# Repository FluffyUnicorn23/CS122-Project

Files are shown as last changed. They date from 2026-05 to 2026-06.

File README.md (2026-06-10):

# CS122A Custom Laboratory Project

# PID Seesaw Balancer

**Ricky Vo and Isaiah Tirado**
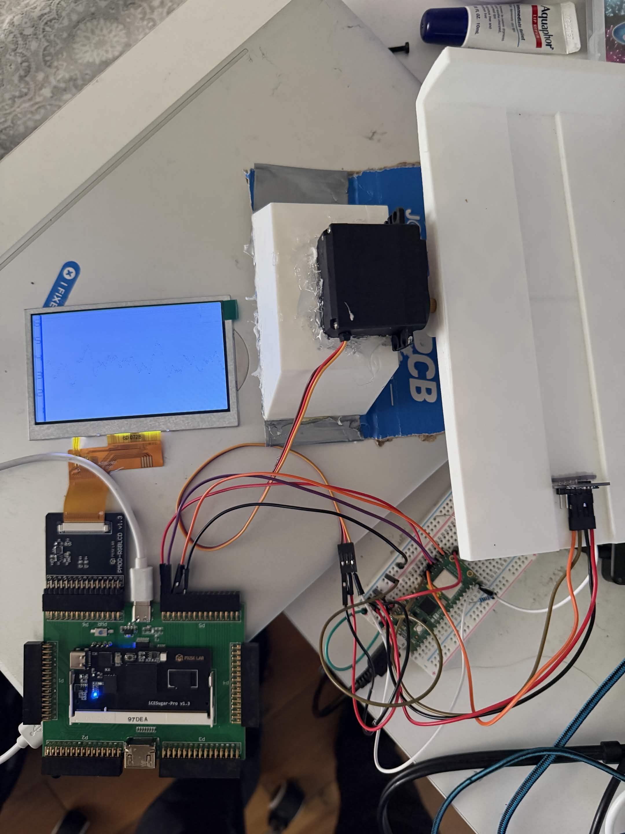
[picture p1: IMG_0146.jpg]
Visual Image

---

# Introduction

A custom printed seesaw attempts to keep a ball as stationary as possible at the target through PID. The seesaw is tilted through a servo motor.

Our PID constants are:

- **Kp = 0.5**
- **Kd = 0.15**
- **Ki = 0.05**
- **Interval Time = 25 ms**

The default target distance used to keep the ball stationary is set to **3 inches** away from the Time-of-Flight sensor. The target distance can be incremented through a button that also starts the balancing procedure, with implemented value rollover.

The distance of the ball from the sensor is tracked through a graph displayed on a screen powered by the FPGA.

Overall, we found that the constants stated above provided the most consistent performance without causing the ball to enter an unstable state.

### Software Issues

- Potential for the system to become unstable.
- Visual display bugs such as double-printed information.

### Hardware Issue

- The seesaw must be manually held down because it is tilted.

---

# Elements of Complexity

- Accurate PID calculations that cause the ball to balance at the desired target.
- Custom designed graph.
- Custom PLA 3D prints designed in OnShape (first time using the software).

---

# User Guide

1. Reset / Power the MCUs.
2. Hold the seesaw down.
3. Place a tennis ball on the seesaw.
4. Press the button.
5. Let it do its magic.
6. Press the button again to increase the target distance.

---

# Hardware Components Used

- IceSugar / IceSugar-Pro FPGA
- RGB LCD from the required lab components
- Raspberry Pi Pico
- MG946R Servo Motor
- VL53L0X Time-of-Flight Sensor
- Custom 3D Printed PLA Seesaw and Complementary Base

---

# Software Libraries Used

- VL53L0X library by yspreen
- pico_stdlib
- Pico I2C library
- Pico SPI library
- Pico PWM library

---

# Protocols Used

## SPI

Used to send information to the FPGA to display necessary data on the RGB LCD.

Signals used:

- MOSI
- CS
- Clock

## I2C

Used for communication with the VL53L0X Time-of-Flight sensor.

- Device Address: `0x29`

---

# Requirements

### IceSugar / IceSugar-Pro FPGA

Used to power and control the information displayed on the RGB LCD screen.

### RGB LCD

Displays positional information of the ball.

### Raspberry Pi Pico

Controls the servo motor, obtains positional information from the Time-of-Flight sensor, and sends information to the FPGA.

### Event Driven Execution

Has a button that turns on the balancing procedure and increments target distance only when pressed.

---

# Wiring Diagram

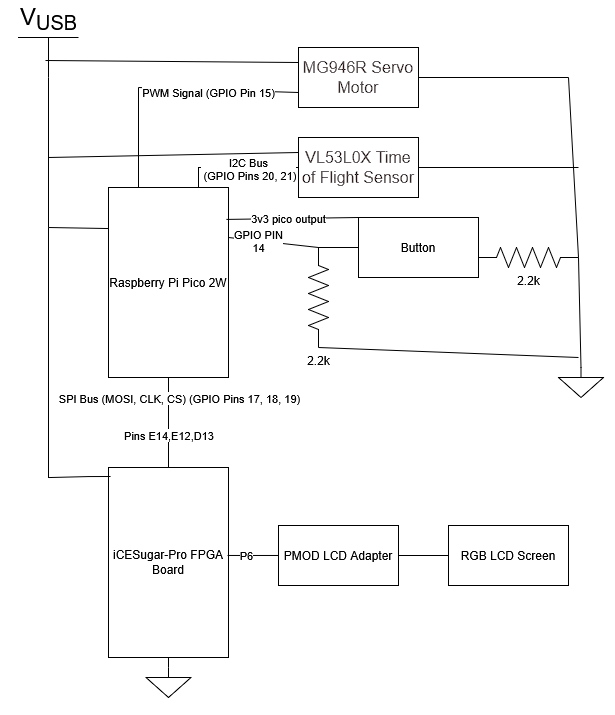
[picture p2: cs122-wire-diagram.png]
Wiring Diagram


---

# Design Diagram

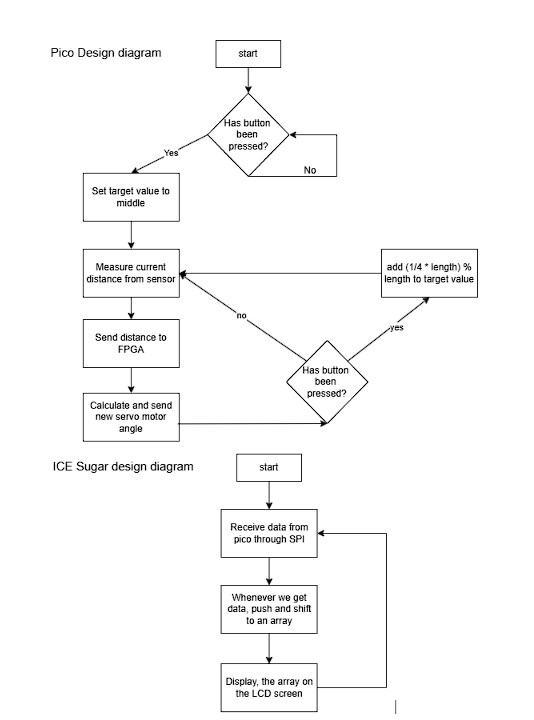
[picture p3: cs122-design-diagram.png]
Design Diagram


---

# AI Usage

**Ricky:** I used AI for the PWM code and the constraint code by asking Google Search.

---

# Acknowledgements

VL53L0X Driver by yspreen:

https://github.com/yspreen/VL53L0X-driver-pico-sdk-cpp/blob/main/VL53L0X.h

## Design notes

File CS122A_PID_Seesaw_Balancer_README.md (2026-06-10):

# CS122A Custom Laboratory Project
## PID Seesaw Balancer

**Authors:** Ricky Vo and Isaiah Tirado

---

## Overview

A custom 3D-printed seesaw balances a ball at a configurable target position using a PID controller. The seesaw angle is adjusted by a servo motor while a VL53L0X Time-of-Flight sensor continuously measures the ball's position.

### PID Configuration

| Parameter | Value |
|---|---|
| Kp | 0.50 |
| Ki | 0.05 |
| Kd | 0.15 |
| Update Interval | 25 ms |

The default target position is **3 inches** from the sensor. A push button starts the balancing process and increments the target distance with rollover behavior. Ball position is displayed graphically on an FPGA-driven LCD screen.

---

## Features

- PID-controlled ball balancing
- Adjustable target position
- Real-time position tracking
- FPGA-powered graphical display
- Custom-designed 3D printed mechanical system
- Event-driven operation through push-button input

---

## Project Complexity

### Control System
- Accurate PID calculations for stable ball balancing
- Real-time feedback control using Time-of-Flight sensing

### Embedded Systems
- Communication between Raspberry Pi Pico and FPGA
- SPI-based display updates
- I2C sensor integration
- PWM servo motor control

### Mechanical Design
- Custom PLA 3D-printed seesaw and base
- Designed using OnShape

---

## User Guide

1. Power on or reset the microcontrollers.
2. Hold the seesaw in place.
3. Place the tennis ball on the seesaw.
4. Press the button to start balancing.
5. Press the button again to increase the target distance.

---

## Hardware Components

| Component | Purpose |
|---|---|
| IceSugar / IceSugar Pro FPGA | LCD control and graphics |
| RGB LCD | Position visualization |
| Raspberry Pi Pico | Main controller |
| MG946R Servo Motor | Seesaw actuation |
| VL53L0X Time-of-Flight Sensor | Ball position sensing |
| Custom 3D Printed PLA Parts | Mechanical structure |

---

## Software Libraries

- Modified VL53L0X library by yspreen
- pico_stdlib
- Pico I2C library
- Pico SPI library
- Pico PWM library

---

## Communication Protocols

### SPI
Used to transmit display information from the Raspberry Pi Pico to the FPGA.

Signals used:
- MOSI
- CS
- Clock

### I2C
Used to communicate with the VL53L0X Time-of-Flight sensor.

- Device Address: `0x29`

---

## System Requirements

### FPGA
Responsible for driving the RGB LCD and rendering project information.

### RGB LCD
Displays ball position and system information.

### Raspberry Pi Pico
- Reads sensor data
- Executes PID calculations
- Controls the servo motor
- Sends display updates to the FPGA

### Event-Driven Operation
Balancing begins only after a button press. Subsequent button presses increment the target position.

---

## System Diagrams

### Wiring Diagram
*(Insert wiring diagram image from report here)*

### Design Diagram
*(Insert design diagram image from report here)*

---

## Known Issues

### Software
- System can occasionally become unstable depending on ball dynamics.
- LCD display may occasionally exhibit graphical artifacts or duplicated text.

### Hardware
- The seesaw must be manually held in position due to the mechanical design.

---

## AI Usage

- PWM code assistance obtained through AI-assisted Google Search.
- Constraint code assistance obtained through AI-assisted Google Search.

---

## Acknowledgements

VL53L0X Driver:
https://github.com/yspreen/VL53L0X-driver-pico-sdk-cpp

---

*CS122A Custom Laboratory Project — PID Seesaw Balancer*

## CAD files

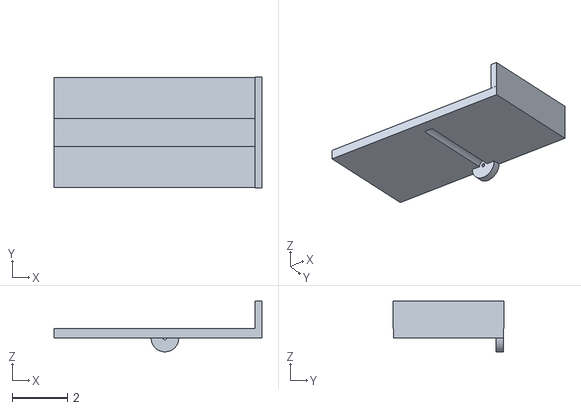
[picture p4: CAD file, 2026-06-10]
Seesaw-Main.stl
7.50 x 4.00 x 1.83

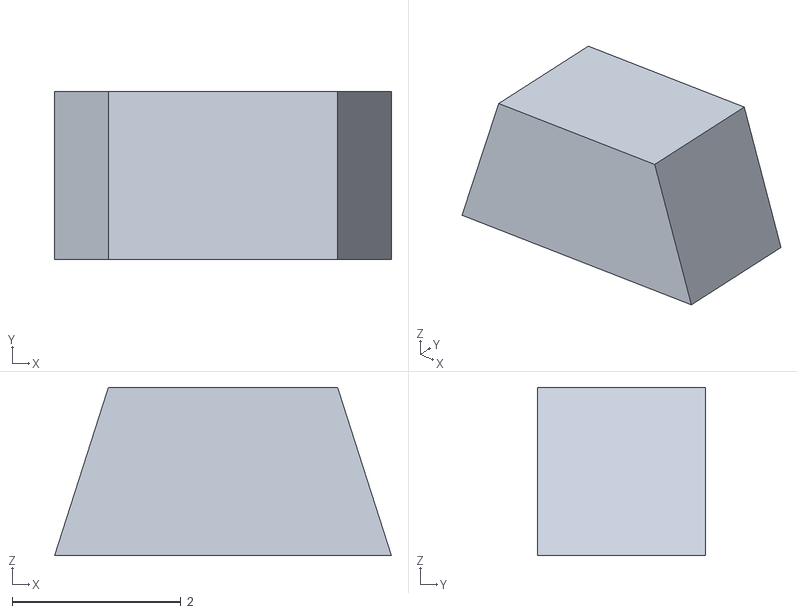
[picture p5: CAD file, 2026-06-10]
Seesaw-Motorbase.stl
4.00 x 2.00 x 2.00

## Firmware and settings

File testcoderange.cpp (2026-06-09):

#include <stdio.h> //measure how fast my calculation ism
#include "pico/stdlib.h"
#include "hardware/i2c.h"
#include "VL53L0X.h"
#include "hardware/pwm.h"
#include "hardware/spi.h"

#define SERVO_PIN 15; // motor pin for pwm

#define SPI_PORT spi0
#define PIN_CS   17
#define PIN_SCK  18
#define PIN_MOSI 19

#define constrain(val, low, high) \ // can be used for multiple types of values
    ((val) < (low) ? (low) : ((val) > (high) ? (high) : (val)))

uint16_t map_dist_to_screen(float dist) {
    return static_cast<uint16_t>(((dist - 1.0) * (251.0 - 10.0)) / 5.0); 
}

void setup_servo() { // used google search
    gpio_set_function(SERVO_PIN, GPIO_FUNC_PWM);
    uint slice_num = pwm_gpio_to_slice_num(SERVO_PIN);
    
    // Set 50Hz PWM cycle (20ms) -> clkdiv / wrap 
    pwm_config config = pwm_get_default_config();
    pwm_config_set_clkdiv(&config, 125.0f); 
    pwm_config_set_wrap(&config, 19999);
    
    pwm_init(slice_num, &config, true);
}

void set_servo_angle(uint slice_num, float angle) { // used google search
    // Convert 0-180 degrees to pulse widths (1ms to 2ms)
    // 1000 = 0 deg, 2000 = 180 deg
    uint pulse_width = 1000 + (angle / 180.0f) * 1000;
    pwm_set_gpio_level(SERVO_PIN, pulse_width);
}

int main() {
    stdio_init_all();
    i2c_init(i2c0, 400 * 1000);
    gpio_set_function(20, GPIO_FUNC_I2C);
    gpio_set_function(21, GPIO_FUNC_I2C);
    gpio_pull_up(20);
    gpio_pull_up(21);

    VL53L0X sensor(i2c0, 0x29);

    if (!sensor.init()) {
        printf("Sensor init failed!\n");
        while (1);
    }

    spi_init(SPI_PORT, 125*1000*1000);
    gpio_set_function(PIN_CS,   GPIO_FUNC_SIO);
    gpio_set_function(PIN_SCK,  GPIO_FUNC_SPI);
    gpio_set_function(PIN_MOSI, GPIO_FUNC_SPI);
    gpio_set_dir(PIN_CS, GPIO_OUT);
    gpio_put(PIN_CS, 1);

    sensor.startContinuous();
    setup_servo();
    uint slice = pwm_gpio_to_slice_num(SERVO_PIN);

    float previous_error = 0.0; 
    float integral = 0.0;
    float target = 2.5; // in inches
    float Kp = 0.5; // most sensititve factor, change this maybe statically 
    float Ki = Kp * 0.1;
    float Kd = Kp * 0.3;
    
    float DT = 0.025;
    float error = 0.0;
    float angle = 90.0;
    set_servo_angle(slice, angle);
    uint8_t tx[1];        
    uint8_t data = 0;

    gpio_init(14);
    gpio_pull_down(14);

    while(!gpio_get(14)){
        printf("Press the button.\n");
    }
    bool lastButtonState = true;

    while (1) {
        bool currentButtonState = gpio_get(14);
        if (lastButtonState && !currentButtonState) {
            if (target + 0.5f > 4.0f) {
                target = 1.5f;
            } else {
                target += 0.5f;
            }
        }
        lastButtonState = currentButtonState;
        uint16_t dist_int = sensor.readRangeContinuousMillimeters(); // stop reading correctly at around an inch
        float dist = (dist_int / 25.40f) - 1.63f; // change minus value for callibration, the higher the number the lower the number
        dist = constrain(dist, 1.0, 6.0);
        //printf("Distance: %.2f inches\n", dist);
        //printf("Target: %.2f inches\n", target);
        data = map_dist_to_screen(dist);
        gpio_put(PIN_CS, 0);
        tx[0] = 251 - data;
        spi_write_blocking(SPI_PORT, tx, 1);
        gpio_put(PIN_CS, 1);
        sleep_ms(25);
        error = target - dist;
        integral += error * DT;
        float derivative = (error - previous_error) / DT;
        float output = Kp*error + Kd*derivative + Ki*integral;
        output = constrain(output, -2.5f, 2.5f);
        //printf("output: %.2f \n", output);
        angle =  90 - output * 10.0;
      
        //printf("Kp: %.2f, Kd: %.2f, Ki: %.2f, Angle: %.2f \n", Kp, Kd, Ki, angle);
        previous_error = error;

        set_servo_angle(slice, angle);
        }      

        
    }   

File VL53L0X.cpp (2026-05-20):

// Most of the functionality of this library is based on the VL53L0X API
// provided by ST (STSW-IMG005), and some of the explanatory comments are quoted
// or paraphrased from the API source code, API user manual (UM2039), and the
// VL53L0X datasheet.

#include "VL53L0X.h"

// Record the current time to check an upcoming timeout against
void VL53L0X::startTimeout()
{
    timeout_start_ms = to_ms_since_boot(get_absolute_time());
}

// Check if timeout is enabled (set to nonzero value) and has expired
bool VL53L0X::checkTimeoutExpired()
{
    return io_timeout > 0 && (to_ms_since_boot(get_absolute_time()) - timeout_start_ms > io_timeout);
}

void VL53L0X::setTimeout(uint16_t timeout)
{
    io_timeout = timeout;
}

uint16_t VL53L0X::getTimeout()
{
    return io_timeout;
}

// Defines /////////////////////////////////////////////////////////////////////

// Decode VCSEL (vertical cavity surface emitting laser) pulse period in PCLKs
// from register value
// based on VL53L0X_decode_vcsel_period()
#define decodeVcselPeriod(reg_val) (((reg_val) + 1) << 1)

// Encode VCSEL pulse period register value from period in PCLKs
// based on VL53L0X_encode_vcsel_period()
#define encodeVcselPeriod(period_pclks) (((period_pclks) >> 1) - 1)

// Calculate macro period in *nanoseconds* from VCSEL period in PCLKs
// based on VL53L0X_calc_macro_period_ps()
// PLL_period_ps = 1655; macro_period_vclks = 2304
#define calcMacroPeriod(vcsel_period_pclks) ((((uint32_t)2304 * (vcsel_period_pclks) * 1655) + 500) / 1000)

// Constructors ////////////////////////////////////////////////////////////////

VL53L0X::VL53L0X(i2c_inst_t *i2cPort, uint8_t address)
{
    this->i2cPort = i2cPort;
    this->address = address;
    // Assuming io_timeout is initialized elsewhere or defaulted to 0
}

// Public Methods //////////////////////////////////////////////////////////////

void VL53L0X::setAddress(uint8_t new_addr)
{
    writeReg(I2C_SLAVE_DEVICE_ADDRESS, new_addr & 0x7F);
    address = new_addr;
}

// Initialize sensor using sequence based on VL53L0X_DataInit(),
// VL53L0X_StaticInit(), and VL53L0X_PerformRefCalibration().
// This function does not perform reference SPAD calibration
// (VL53L0X_PerformRefSpadManagement()), since the API user manual says that it
// is performed by ST on the bare modules; it seems like that should work well
// enough unless a cover glass is added.
// If io_2v8 (optional) is true or not given, the sensor is configured for 2V8
// mode.
bool VL53L0X::init(bool io_2v8)
{
    printf("model: ");
    printf("%d\n", readReg(IDENTIFICATION_MODEL_ID));
    // check model ID register (value specified in datasheet)
    if (readReg(IDENTIFICATION_MODEL_ID) != 0xEE)
    {
        return false;
    }

    // VL53L0X_DataInit() begin

    // sensor uses 1V8 mode for I/O by default; switch to 2V8 mode if necessary
    if (io_2v8)
    {
        writeReg(VHV_CONFIG_PAD_SCL_SDA__EXTSUP_HV,
                 readReg(VHV_CONFIG_PAD_SCL_SDA__EXTSUP_HV) | 0x01); // set bit 0
    }

    // "Set I2C standard mode"
    writeReg(0x88, 0x00);

    writeReg(0x80, 0x01);
    writeReg(0xFF, 0x01);
    writeReg(0x00, 0x00);
    stop_variable = readReg(0x91);
    writeReg(0x00, 0x01);
    writeReg(0xFF, 0x00);
    writeReg(0x80, 0x00);

    // disable SIGNAL_RATE_MSRC (bit 1) and SIGNAL_RATE_PRE_RANGE (bit 4) limit checks
    writeReg(MSRC_CONFIG_CONTROL, readReg(MSRC_CONFIG_CONTROL) | 0x12);

    // set final range signal rate limit to 0.25 MCPS (million counts per second)
    setSignalRateLimit(0.25);

    writeReg(SYSTEM_SEQUENCE_CONFIG, 0xFF);

    // VL53L0X_DataInit() end

    // VL53L0X_StaticInit() begin

    uint8_t spad_count;
    bool spad_type_is_aperture;
    if (!getSpadInfo(&spad_count, &spad_type_is_aperture))
    {
        return false;
    }

    // The SPAD map (RefGoodSpadMap) is read by VL53L0X_get_info_from_device() in
    // the API, but the same data seems to be more easily readable from
    // GLOBAL_CONFIG_SPAD_ENABLES_REF_0 through _6, so read it from there
    uint8_t ref_spad_map[6];
    readMulti(GLOBAL_CONFIG_SPAD_ENABLES_REF_0, ref_spad_map, 6);

    // -- VL53L0X_set_reference_spads() begin (assume NVM values are valid)

    writeReg(0xFF, 0x01);
    writeReg(DYNAMIC_SPAD_REF_EN_START_OFFSET, 0x00);
    writeReg(DYNAMIC_SPAD_NUM_REQUESTED_REF_SPAD, 0x2C);
    writeReg(0xFF, 0x00);
    writeReg(GLOBAL_CONFIG_REF_EN_START_SELECT, 0xB4);

    uint8_t first_spad_to_enable = spad_type_is_aperture ? 12 : 0; // 12 is the first aperture spad
    uint8_t spads_enabled = 0;

    for (uint8_t i = 0; i < 48; i++)
    {
        if (i < first_spad_to_enable || spads_enabled == spad_count)
        {
            // This bit is lower than the first one that should be enabled, or
            // (reference_spad_count) bits have already been enabled, so zero this bit
            ref_spad_map[i / 8] &= ~(1 << (i % 8));
        }
        else if ((ref_spad_map[i / 8] >> (i % 8)) & 0x1)
        {
            spads_enabled++;
        }
    }

    writeMulti(GLOBAL_CONFIG_SPAD_ENABLES_REF_0, ref_spad_map, 6);

    // -- VL53L0X_set_reference_spads() end

    // -- VL53L0X_load_tuning_settings() begin
    // DefaultTuningSettings from vl53l0x_tuning.h

    writeReg(0xFF, 0x01);
    writeReg(0x00, 0x00);

    writeReg(0xFF, 0x00);
    writeReg(0x09, 0x00);
    writeReg(0x10, 0x00);
    writeReg(0x11, 0x00);

    writeReg(0x24, 0x01);
    writeReg(0x25, 0xFF);
    writeReg(0x75, 0x00);

    writeReg(0xFF, 0x01);
    writeReg(0x4E, 0x2C);
    writeReg(0x48, 0x00);
    writeReg(0x30, 0x20);

    writeReg(0xFF, 0x00);
    writeReg(0x30, 0x09);
    writeReg(0x54, 0x00);
    writeReg(0x31, 0x04);
    writeReg(0x32, 0x03);
    writeReg(0x40, 0x83);
    writeReg(0x46, 0x25);
    writeReg(0x60, 0x00);
    writeReg(0x27, 0x00);
    writeReg(0x50, 0x06);
    writeReg(0x51, 0x00);
    writeReg(0x52, 0x96);
    writeReg(0x56, 0x08);
    writeReg(0x57, 0x30);
    writeReg(0x61, 0x00);
    writeReg(0x62, 0x00);
    writeReg(0x64, 0x00);
    writeReg(0x65, 0x00);
    writeReg(0x66, 0xA0);

    writeReg(0xFF, 0x01);
    writeReg(0x22, 0x32);
    writeReg(0x47, 0x14);
    writeReg(0x49, 0xFF);
    writeReg(0x4A, 0x00);

    writeReg(0xFF, 0x00);
    writeReg(0x7A, 0x0A);
    writeReg(0x7B, 0x00);
    writeReg(0x78, 0x21);

    writeReg(0xFF, 0x01);
    writeReg(0x23, 0x34);
    writeReg(0x42, 0x00);
    writeReg(0x44, 0xFF);
    writeReg(0x45, 0x26);
    writeReg(0x46, 0x05);
    writeReg(0x40, 0x40);
    writeReg(0x0E, 0x06);
    writeReg(0x20, 0x1A);
    writeReg(0x43, 0x40);

    writeReg(0xFF, 0x00);
    writeReg(0x34, 0x03);
    writeReg(0x35, 0x44);

    writeReg(0xFF, 0x01);
    writeReg(0x31, 0x04);
    writeReg(0x4B, 0x09);
    writeReg(0x4C, 0x05);
    writeReg(0x4D, 0x04);
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

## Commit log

2026-05-20 Sensor code
2026-05-21 Added motor and sensor combo
2026-05-28 Implement PID control for servo
    Added PID control for servo angle adjustment based on distance readings.
2026-06-09 Refactor servo control and add SPI communication
2026-06-09 Refactor CMakeLists.txt for Pico SDK configuration
2026-06-10 Update CMakeLists.txt for Pico project configuration
2026-06-10 Add README for PID Seesaw Balancer project
    Add detailed project documentation for the PID Seesaw Balancer, including features, user guide, hardware components, software libraries, communication protocols, system requirements, known issues, and acknowledgements.
